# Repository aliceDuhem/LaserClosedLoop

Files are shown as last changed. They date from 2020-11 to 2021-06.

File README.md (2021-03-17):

# LaserClosedLoop

### Essential Libraries Needed:

> Ni-Visa <br />
> Visa <br />
> Guizero <br />
> ThorlabsPM100 <br />
> Pyusb <br />

### Codes needed to run (yet to interlink):

LaserControl<br />
&nbsp;&nbsp;&nbsp;&nbsp;&nbsp;&nbsp;  | <br />
&nbsp;&nbsp;&nbsp;&nbsp;&nbsp;&nbsp;  | <br />
&nbsp;&nbsp;&nbsp;&nbsp;&nbsp;&nbsp;  |-- ratioCodes (Mathematical algorithm returning angle closest to desired intensity) <br />
&nbsp;&nbsp;&nbsp;&nbsp;&nbsp;&nbsp;  | <br />
&nbsp;&nbsp;&nbsp;&nbsp;&nbsp;&nbsp;  |-- GetPower (Initialise and read power meter values) <br />
&nbsp;&nbsp;&nbsp;&nbsp;&nbsp;&nbsp;  | <br />
&nbsp;&nbsp;&nbsp;&nbsp;&nbsp;&nbsp;  |-- Motor_calibration (Motor calibration during power on) <br />
&nbsp;&nbsp;&nbsp;&nbsp;&nbsp;&nbsp;  | <br />
&nbsp;&nbsp;&nbsp;&nbsp;&nbsp;&nbsp;  |-- characteristics (Class to hold specs of the system) <br />
&nbsp;&nbsp;&nbsp;&nbsp;&nbsp;&nbsp;  | <br />
&nbsp;&nbsp;&nbsp;&nbsp;&nbsp;&nbsp;  |-- ControlCode (PID control)  <br />
&nbsp;&nbsp;&nbsp;&nbsp;&nbsp;&nbsp;  | <br />
&nbsp;&nbsp;&nbsp;&nbsp;&nbsp;&nbsp;  |-- App2 (UI for users to input desired intensity and optical properties of system) <br />

### Testing Functions:

LaserControl<br />
&nbsp;&nbsp;&nbsp;&nbsp;&nbsp;&nbsp; |<br />
&nbsp;&nbsp;&nbsp;&nbsp;&nbsp;&nbsp; |<br />
&nbsp;&nbsp;&nbsp; Tests <br />
&nbsp;&nbsp;&nbsp;&nbsp;&nbsp;&nbsp;&nbsp;&nbsp;   | <br />
&nbsp;&nbsp;&nbsp;&nbsp;&nbsp;&nbsp;&nbsp;&nbsp;  | <br />
&nbsp;&nbsp;&nbsp;&nbsp;&nbsp;&nbsp;&nbsp;&nbsp;  |-- SaveDataCsv (Function to write output array into csv for analysis) <br />
&nbsp;&nbsp;&nbsp;&nbsp;&nbsp;&nbsp;&nbsp;&nbsp;  | <br />
&nbsp;&nbsp;&nbsp;&nbsp;&nbsp;&nbsp;&nbsp;&nbsp;  |-- testDictCode (Tests dictionary to verify its theoretical functionality) <br />
&nbsp;&nbsp;&nbsp;&nbsp;&nbsp;&nbsp;&nbsp;&nbsp;  | <br />
&nbsp;&nbsp;&nbsp;&nbsp;&nbsp;&nbsp;&nbsp;&nbsp;  |-- TestDictionaryWithPowerMeter (Tests interlinkage between dictionary and power meter) <br />
&nbsp;&nbsp;&nbsp;&nbsp;&nbsp;&nbsp;&nbsp;&nbsp;  | <br />
&nbsp;&nbsp;&nbsp;&nbsp;&nbsp;&nbsp;&nbsp;&nbsp;  |-- findDifference (Tests mathematical rigour of dictionary codes) <br />

### Matlab commands to test theory:

MatlabStuff<br />
&nbsp;&nbsp;&nbsp;&nbsp;&nbsp;&nbsp;  | <br />
&nbsp;&nbsp;&nbsp;&nbsp;&nbsp;&nbsp;  | <br />
&nbsp;&nbsp;&nbsp;&nbsp;&nbsp;&nbsp;  |-- Jone1 (Made jones matrices in matlab and derived initial ratios) <br />

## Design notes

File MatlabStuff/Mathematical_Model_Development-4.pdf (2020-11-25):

# Mathematical Model of Output Intensity

November 25, 2020

## 1 Visual representation of the system

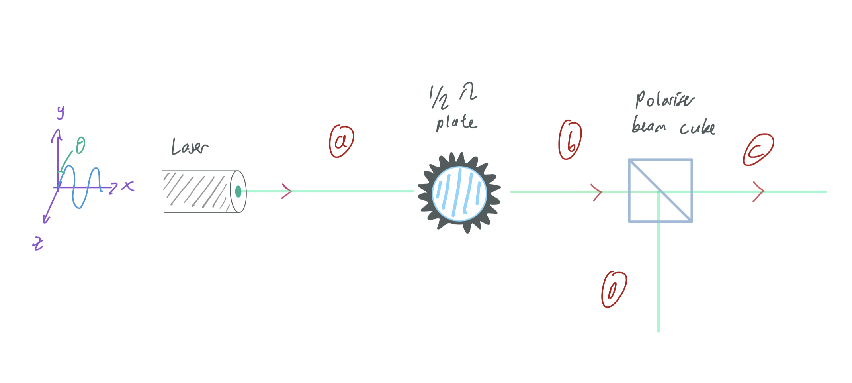
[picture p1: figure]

Figure 1: Path of laser

Figure above shows the path of the laser and the optical components which modulates it. A mathematical model of Fig.1 must be made and Incorporated into the control code so output can be tuned accordingly.

Laser Specs, CPS532-C2:

1. Output linearly polarised in the Ey direction
2. Beam diameter, 3.5mm
3. Gaussian beam
4. 532 nm, frequency changes with temprature
5. 0.9 mW Power
6. Impedance of free space, η = 376.7303Ω

Half Wave Plate Specs, WPH05ME-532:

1. reflectance 0.25% @ 532nm
2. Transmittance 98.04996% @ 532nm

Polarising Beam Cube Specs, PBS121:

1. P-pol transmittance 95.54% @ 532nm
2. S-pol transmittance 0.04348% @ 532nm (ignore too small)
3. S-pol reflectance > 99.50% @ 532nm

1

Section 3 Updates

### 1.1 Jones Matrix

A Jones Matrix for each system component has to be made. Jones matrices make it easier to look at the system as a whole as it captures both axis at the same time. It can also be thought as a transfer function.

### 1.1.1 Polarising Beam Cube

Figure 2: P=ŷ, S=ẑ

This cube allows ŷ waves to be transmitted through to C, while reflecting ẑ to path D. Thus, we can imagine the cube to have 2 polarisers, for path C in Fig.1 the fast axis is in the ŷ direction. While for path D fast axis is in zˆ.

Suppose Beam Cube from Fig.1 has a fast axis in the ŷ direction. An electromagnetic wave vector E~ can be split into it’s components.
Ey
Ez
, axis

defined in Fig.1. Now lets create its Jones Matrix. If a purely horizontally polarised EM wave passes through it, E~
x =
0
1
zˆ the output would be the nil
0
0
zˆ as incident wave is perpendicular to its axis. If a purely vertically polarised wave passes it, E~
x =
1
0

yˆ output would also be
1
0
yˆ as incident wave and fast axis align. We can combine both the output matrix

together to form the Jones matrix at Fig.1 C. J =
1 0

0 0

The above can be repeated to find the Jones matrix for the polariser in the ẑ direction.
1
0

yˆ −→
0
0
,
0
1

zˆ −→
0
1

J =

0 0

0 1
(1)

1.1.2 1/2 Wave Plate

Half wave plate works as a retarder, slowing down each of the axis independently. This is caused by bifrin-gence where the crystal has 2 different refractive indexes for each of its axis. We call refractive index in the fast axis nf and slow axis ns. In Fig.1 the fast axis of the wave plate originally lies in the ŷ direction.

A linearly polarised wave travelling in the ˆx direction can be given the equation (2). After passing the wave plate it emerges with modified terms (3) as a phase difference is introduced.

E~
x = ŷEoe

j(ωt−kx)
(2)

E~
x = ŷEoe

j(ωt−konfL)

= ẑEoe

−jkonfL
e

j(ωt−kz)

(3)

e

−jkonfL is the phase difference

ko=wave number, nf=fast axis index, L=length of waveplate, Eo=incident wave amplitude, ω=Angular frequency, t=time

Like the polarising beam cube, we intend to find the Jones matrix. So we input waves in ŷ and ẑ to find its response.
1
0

yˆ −→
e

−jkonfL
0
,
0
1

zˆ −→
0
e

−jkonsL

We combine both to make (4) which is the phase relative to incident.
e
−jkonfL | 0
0 | e −jkonsL
(4)

Multiply (4) by e

jkonfL
1 | 0
0 e

−jko(nf −ns)L

(5)

∆n = nf − ns and L =

λo
2∆n

Therefore its Jones matrix is:
1 0
0 −1
(6)

1.2 1/2 Wave Plate Rotating Jones Matrix

Jones matrix only works for a fixed theta, since our system requires the half wave plate to rotate we have to modify (6) by multiplying a rotation matrix term R(θ) to find Jnew.

Jnew = R(θ)JcurrentR(θ)

−1

R(θ) =
cos(θ) − sin θ
sin θ cos θ

(7)

By substituting (6) and finding the inverse of R(θ) we get (8) which was calculated in matlab, complex!

Jnew =

cos

π θ

180 2
− sin

π θ

180 2
2 cos

π θ
180

sin

π θ
180
2 cos

π θ
180

sin

π θ
180

sin

π θ

180 2
− cos

π θ

180 2

!
(8)

## 2 Combining it together

Order of multiplication is important, we start by multiplying leftwards components in Fig.1. Remember in this case the polarisers fast axis is in the ŷ direction.

Eoutput = Jcube ∗ Jwaveplate ∗ Einput | (9)

### 2.1 Output at Fig.1 C

(9) gives us the output amplitude as a function of θ, Ey and Ez. Notice there is no Ez term, remember the polariser is aligned with the ŷ axis so it totally blocks any ẑ component.

E~
c,out =

Ey
cos

π θ

180 2
− sin

π θ

180 2

+ 2 Ez cos

π θ
180

sin

π θ
180

0

!
(10)

### 2.2 Output at Fig.1 D

Sin | and | Cos | contained | | within | equations | | of this | paper | | are | calculated | in | radians | (matlab | default). | So | θ | which
is | in | degrees | | has | to | be | multiplied | | by | π
180 //
Remember in this case the polariser’s fast axis is in the ẑ direction. Notice that there is no Ey component as the polarising beam cube only reflects ẑ So using (9) we get

E~
d,out =

0
2 Ey cos

π θ
180

sin

π θ
180

− Ez
cos

π θ

180 2
− sin

π θ

180 2

!
(11)

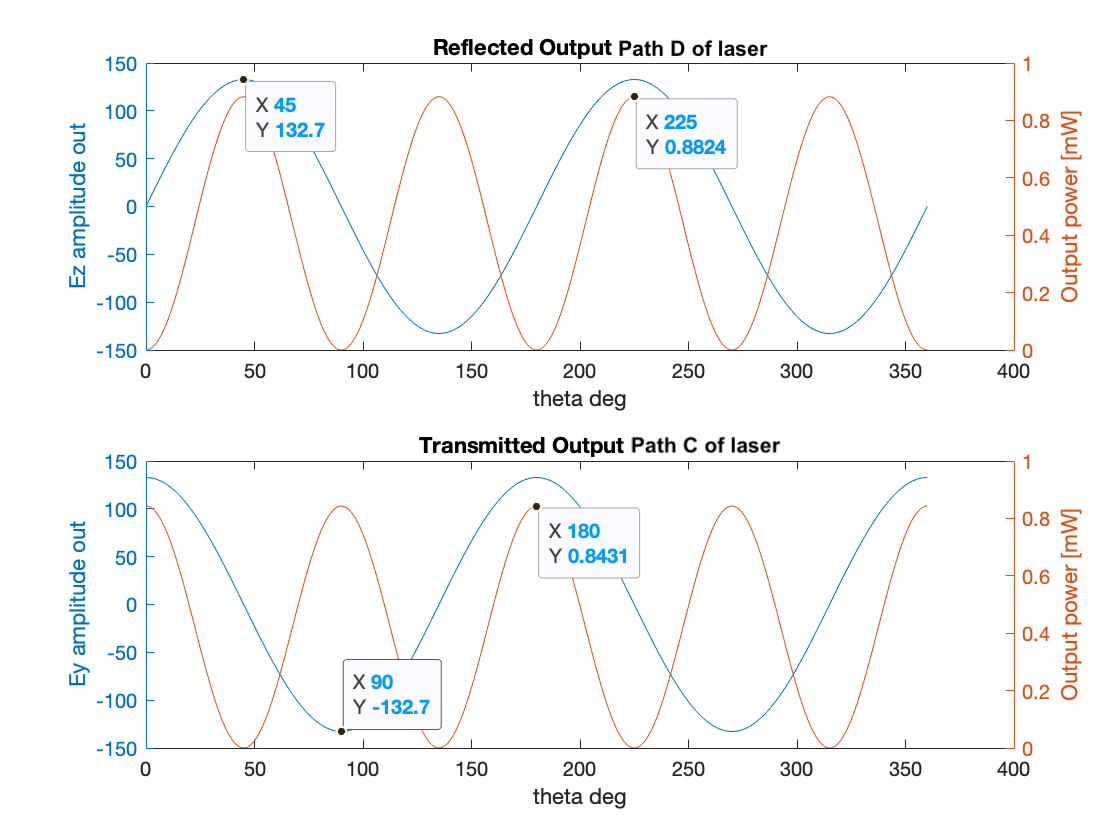
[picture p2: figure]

Figure 3: Output for Path C and D

Theta is the angle of rotation of the half wave plate relative to its fast axis pointing towards ŷ. We can theoretically sustain full range 0 to Max power with a rotation range of π/2. After including the transmission coefficients, the maximum power would be less at a max of 0.8431mW. EyandEz are phase shifted from each other by π/4.

Power of Ey also has a factor of 0.9554 multiplied to it relative to Ez (checked by isolating regions with the same shape and divided those regions, constant factor found). Both graphs are essentially the same by adding a phase shift and a factor to one of the outputs (checked by plotting with matlab).

Might | use | DTFT | to | add | time | shift, | P owerEy = 0.9554P owerEz+ | phase | shift, | π/2 | factor | is just | the | P-Pol
transmittance.

### 2.3 Equation Relating both Power at C & D

Total intensity can be found by relating eqn (10) and (11):

Itotal = Ctλt

E²
c
2η

+ λt

E²
d
2η

=

λt
2η

(CtE

2
c + E

2
d

)

(12)

ct is cube transmittance, λt is waveplate transmittance.
Total power can be found by multiplying total intensity with area:

Ptotal = Itotal ∗ BeamArea

Pc + Pd = A

λt
2η

(CtE

2
c + E

2
d

)

(13)

Expanding the above, we see that the final equation relies on 3 variables, Pc, Pd and θ in degrees.

Pc + Pd = AE²
y

λt
2η

(Ct(cos²
(

πθ
180

) − sin²
(

πθ
180

) + 4cos²
(

πθ
180

)sin²
(

πθ
180
)) | (14)

The terms after the = sign represent the fluctuating power output as a sum of both split beams. This is caused by the difference in transmittivity for P and S pol in the beam cube.

The equation (14) essentially deducts the sensor power from the total power (with regards to θ) to find power in path C.

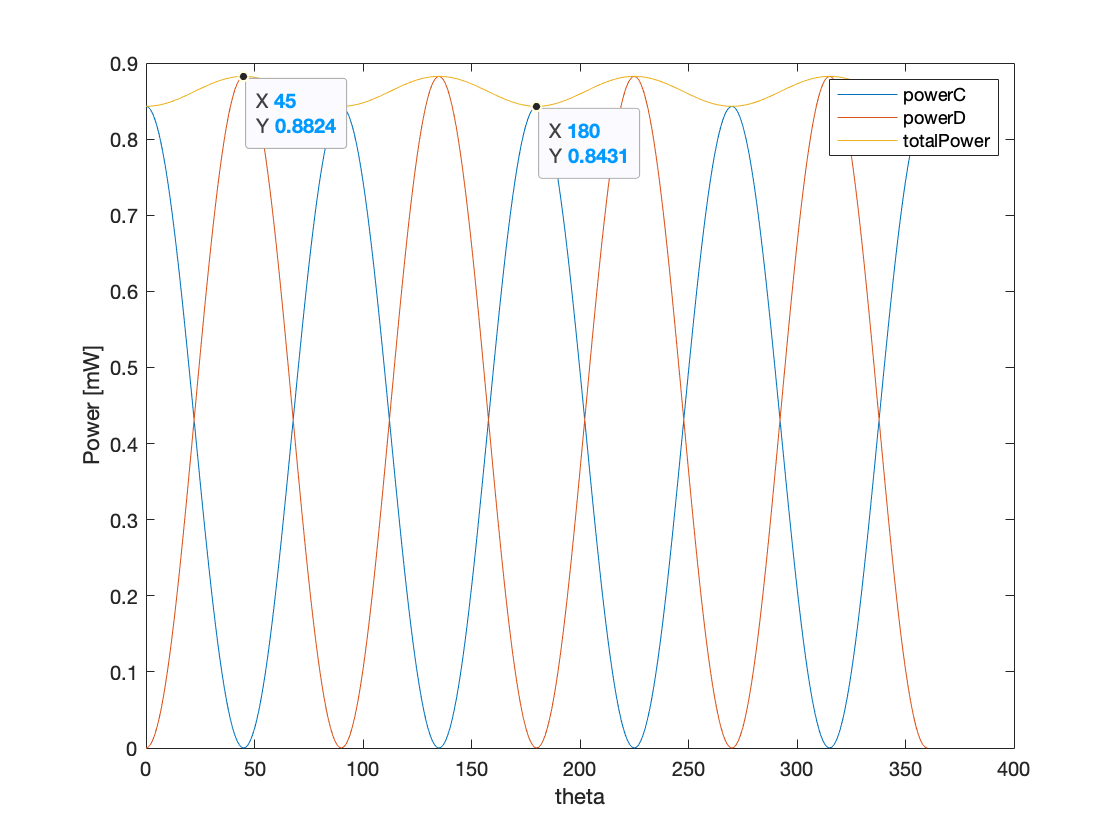
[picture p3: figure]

Figure 4: Power vs theta

UNFORTUNATELY | | | | (14) | CONTAINS | | LASER | VARIABLES | | FROM | THE | ORIGINAL | | LASER | INPUT
WHICH | IS | THEORETICALLY | | | | CONSTANT. | | THIS | DOES | NOT | TAKE | INTO | ACCOUNT | | THE | FLUC-
TUATIONS | | | OF | THE | LASER | ITSELF. | | INVERSE | | FOR | θ | HARD | TO | FIND | as | shown | in | the | long | equation
(15) below

−

ln

16384000 √
(500000 T Z−4405109641 A L) (137438953472 T Z−1210867317976915 A C L)−4294967296000000 T Z+18919801843389300736 A L+18919801843389296875 A C L
18919801843389300736 A L−18919801843389296875 A C L | 1/4

π
(15)
3 | POSSIBLE | BREAKTHROUGH

Looking at figure 3. There is a possible connection between both output power except the obvious phase shifts.

By dividing powerC/powerD I get the figure below. This does not change with the change with different laser intensity. The transmittance of the optical elements cause it to change as explained below.

intensity =

E

2
2η
power = intensity ∗ area

Since we’re dividing Power C by Power D, and beam area is assumed to be constant, the area cancels out. This gives us the individual intensities for both path C and D. Don’t forget to multiply by transmittance of half wave plate λt and cube Ct.

ID = λt

E²
z
2η

IC = λtCt

E²
y
2η
Ratio, PC
PD

=

IC
ID

= Ct

E²
y
E²
z

(16)

We get the ratio which can be seen in Fig. 5. Ratio changes with theta and at multiples of 0, 45 deg the ratio will be 0. So this means at multiples of 0 and 90 deg power D will be 0. This is the same for power C at multiples of 45 deg. This can be confirmed by referring to Fig. 3

Ratio scaled based on cube transmittance Ct and not half wave plate as they cancel out. If the cube reflected tramsmittance is significant, te scale would instead be, Ct Ref.T rans.

We now can relate the Power C and Power D without the original laser input. This can be done by checking the motor angle and referring to the ratio dataset to calculate the corresponding power. The datapoints can be found in github to be used! https://github.com/aliceDuhem/LaserClosedLoop

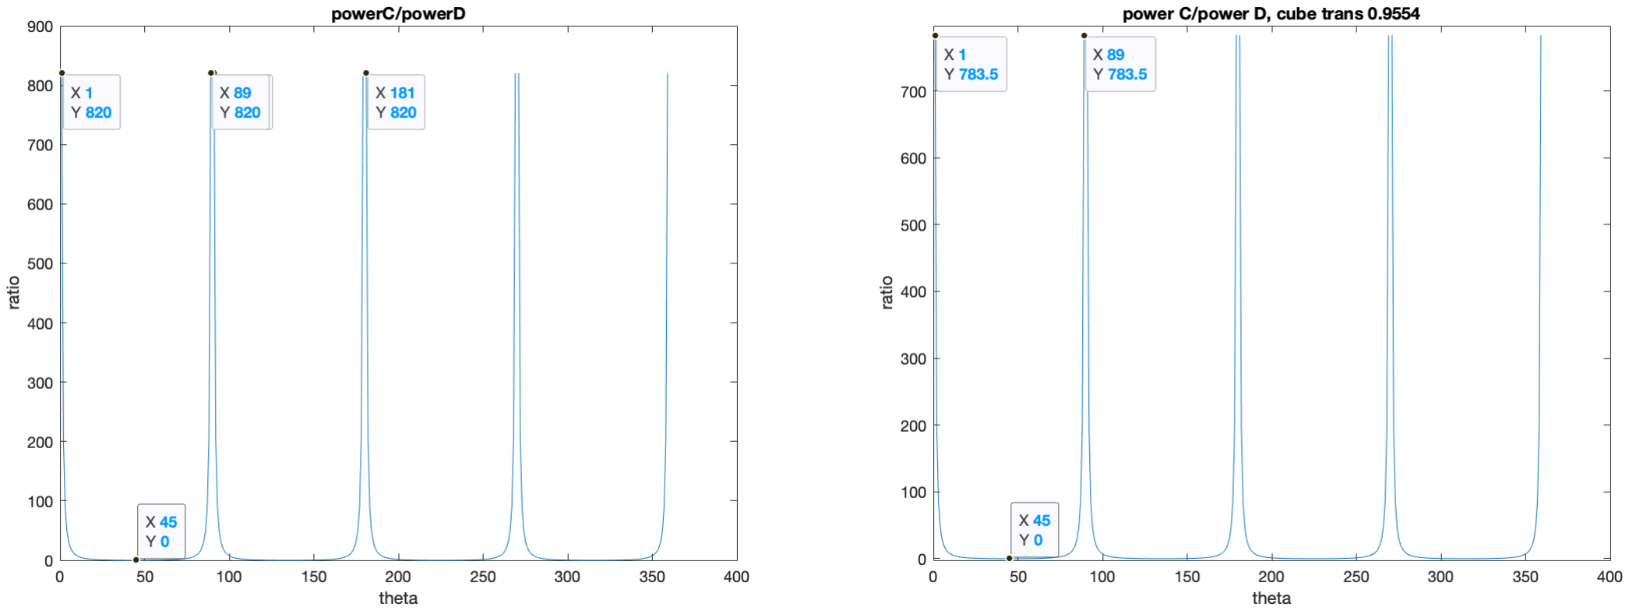
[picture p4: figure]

Figure 5: PowerD:PowerC

4 | Comparison with Malus Law | Ignore

Malus Law states that output intensity, Io, is proportional to cos² θ, when a wave passes a linear polariser.

Io = Iin cos²
θ | (17)

In Fig.6 we can see that Jones has an angular velocity twice that of Malus. Transmission coefficients have been incorperated into the calculations for the graph. Both have the same peak, thus we are able to model ALL the above with (18) instead, but keep in mind to add the transmission coefficients.

Io = Iin cos²
2θ | (18)

Iin contains the original intensity, cube P-pol transmittance, wave plate transmittance.

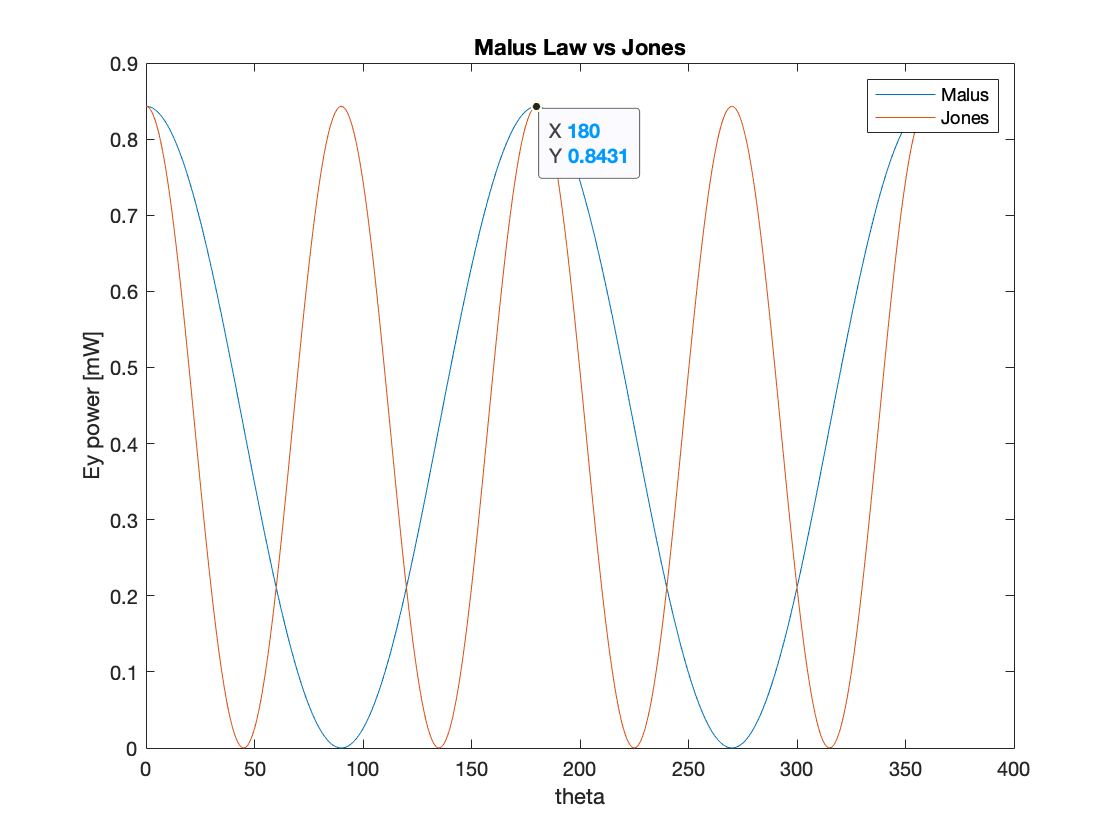
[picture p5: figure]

Figure 6: Malus VS Jones in Path C

## Appendix A MATLAB Code

clc
clear all
close all

% polarizing beam cube errors and specs (reflects s-pol) % p-pol transmittance 95.54% @ 532nm
% s-pol transmittance 0.04348% @ 532nm
% total R_s > 99.50%
cubeP_trans = 0.9554;
cubeS_trans = 0.0004348; %this not needed as the max difference in power is 3.83e-4 mW

% half wave plate errors and specs
% reflectance 0.25% @ 532nm
% transmittamnce 98.04996% @ 532nm

halfWave_trans = 0.9804996; % incldue as mean sqr err between original and transmitted Ey ,→ = 0.8482

% laser spec and error
% 0.8mW < power < 1mW, typical @ 0.9mW % frequency changes with temprature

%% Find transmitted output Ey

% use jones matrix to find 'transfer function' of whole system

syms theta Ey Ez;

r = [cosd(theta) -sind(theta);sind(theta) cosd(theta)]; rInv = inv(r);

JonesHalf = [1 0;0 -1];
JonesPol=[1 0 ; 0 0];
JonesHalfRot = r*JonesHalf*rInv;
initial =[Ey; Ez]; % only adjust Ey becsaue laser linearly pol. % keep Ez as 0, laser pol in Y direc only. % adjust in bottom {} brackets
TotalTrans = JonesPol*JonesHalfRot | * initial;
thetaAxis =[0:1:360]; | % adjust division accodring to servo motor

for i=1:size(thetaAxis,2)

solT = subs (TotalTrans, {theta, Ey,Ez} ,{thetaAxis(i),132.742,0});

outEy(i) = double(solT(1));
outEz(i) = double(solT(2));
end

% plot theta against Ey proportion
% Ez remains 0 as 2nd polariser cuts it off figure(1)
subplot(2,1,2)

yyaxis left
plot(thetaAxis,outEy)
xlabel('theta')
ylabel('Ey amplitude out') title('Transmitted Output Ey of laser')

hold on
intensity = cubeP_trans .* halfWave_trans .* outEy.^2 ./ (2.*376.7303); %include transmittance above
power = intensity .* (pi.*(3.5e-3.^2));

yyaxis right
plot(thetaAxis,power.*1000) xlabel('theta deg')
ylabel('Output power [mW]')

%% test with malus law instead of jones

intensity1 = 0.9e-3 / (pi*(3.5e-3^2));
intensity1Out = cubeP_trans .* halfWave_trans .* intensity1 .* cosd(thetaAxis).^2;

figure plot(thetaAxis,intensity1Out.*1000.* (pi.*(3.5e-3.^2)),thetaAxis, power.*1000) legend('Malus','Jones')
ylabel('Ey power [mW]')
xlabel('theta')
title('Malus Law vs Jones')

% intensity - intensity1Out gave a mean squared error of 1.5903e-10, which % is neglegable. So i suggest we ignore it.
% this shows that my equations are very close to malus law

%% reflected output Ez to detector

JonesPolRef=[0 0 ; 0 1];
JonesHalfRot = r*JonesHalf*rInv;
TotalRef = JonesPolRef * JonesHalfRot * initial;

for i=1:size(thetaAxis,2)

solT = subs (TotalRef, {theta, Ey,Ez} ,{thetaAxis(i),132.742,0});

outRefEy(i) = double(solT(1));
outRefEz(i) = double(solT(2));
end

figure(1)
subplot(2,1,1)
yyaxis left
plot(thetaAxis,outRefEz)
xlabel('theta')
ylabel('Ez amplitude out') title('Reflected Output Ez of laser')
hold on

intensityRef = halfWave_trans.* outRefEz.^2 ./ (2.*376.7303); powerRef = intensityRef .* (pi.*(3.5e-3.^2));

% figure
yyaxis right
plot(thetaAxis,powerRef.*1000) xlabel('theta deg')
ylabel('Output power [mW]')
% title('Power vs theta')

%% Ez and Ey between half wave and cube

between = JonesHalfRot * initial;

for i=1:size(thetaAxis,2)

solBet = subs (between, {theta, Ey,Ez} ,{thetaAxis(i),132.742,0});

BetEy(i) = double(solBet(1));
BetEz(i) = double(solBet(2));

end

figure
hold on
plot(thetaAxis, sqrt(halfWave_trans).* BetEy, thetaAxis, sqrt(halfWave_trans).*BetEz) plot(thetaAxis, BetEy, thetaAxis, BetEz)
% legend('Ey','Ez')

%% plot path C including s-pol
% cannot use equaton outEY as that contains final transform % can ignore as difference too small 1e-4 mW in power

FinalEz = BetEz.*sqrt(halfWave_trans).*sqrt(cubeS_trans); FinalEy = BetEy.*sqrt(halfWave_trans).*sqrt(cubeP_trans); % outEy = outEy .* sqrt(halfWave_trans);

Etot = sqrt(FinalEz.^2 + FinalEy.^2);

intensityNew = Etot.^2 ./ (2.*376.7303); powerNew = intensityNew .*(pi.*(3.5e-3.^2)); figure
plot(thetaAxis, powerNew*1000)

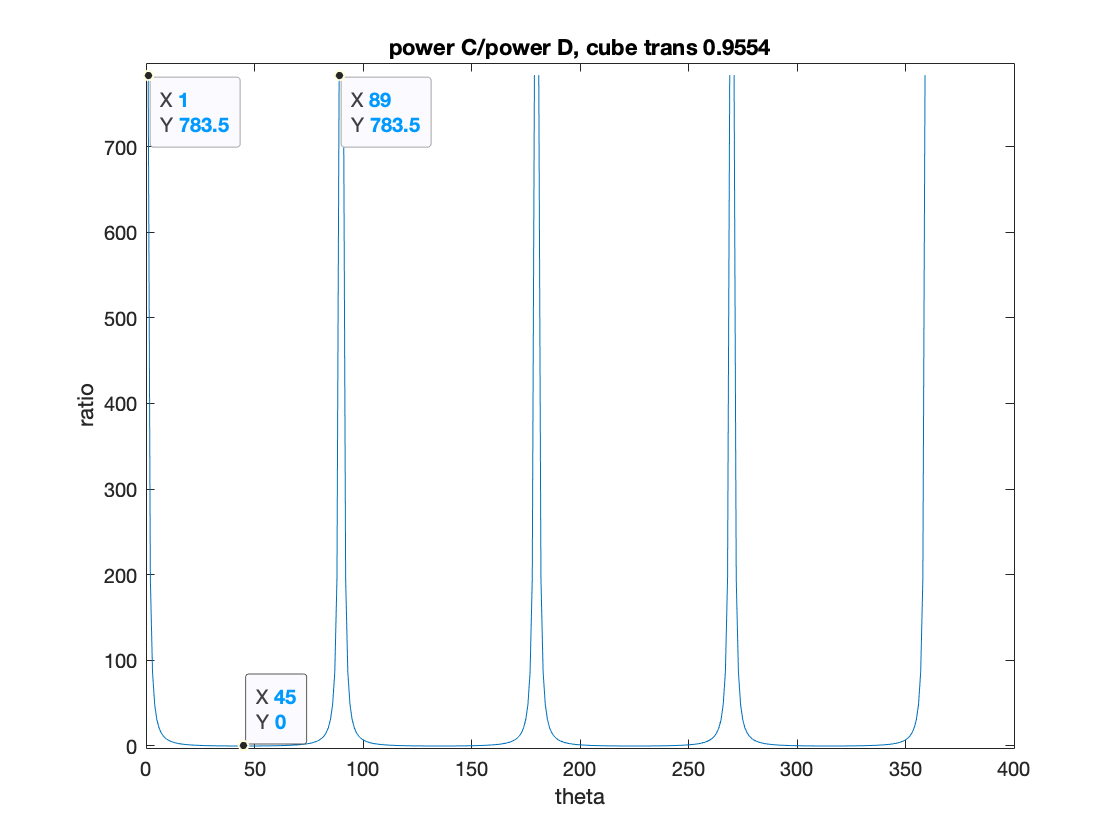
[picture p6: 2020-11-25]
MatlabStuff/ratio1.png

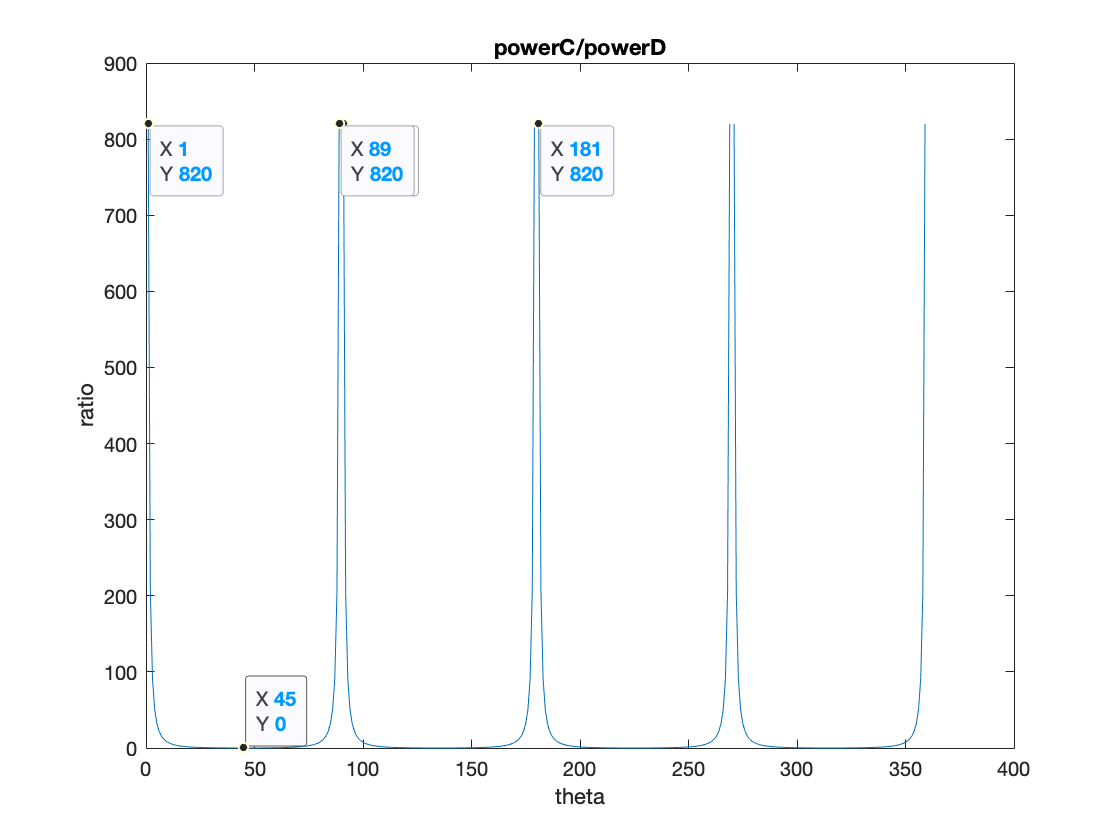
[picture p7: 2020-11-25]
MatlabStuff/ratio.png

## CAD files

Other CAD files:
Solidwork mechanical stands parts/Beam cube case/final_beam_cube.ipt
Solidwork mechanical stands parts/Beam cube case/final_beam_cube_top.ipt
Solidwork mechanical stands parts/HWP rotating mount/Bottom_stand_HWP_Tube.ipt
Solidwork mechanical stands parts/HWP rotating mount/Top_stand_HWP_Tube.ipt
Solidwork mechanical stands parts/Laser case/laser bottom.ipt
Solidwork mechanical stands parts/Laser case/laser top.ipt
Solidwork mechanical stands parts/Linear Polariser case/linear polariser.ipt
Solidwork mechanical stands parts/bottom_platform/platform_part_1.ipt
Solidwork mechanical stands parts/bottom_platform/platform_part_2.ipt

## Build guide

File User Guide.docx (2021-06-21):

User Guide to the device

Components needed

- Power meter and a photodiode power sensor: Reads the laser power refracted from the beam cube
- Optics:
  - Polariser: linearly polarise the light in case the laser is elliptically polarised
  - Half Wave Plate: Changes the polarisation angle of the linearly polarised light
  - Beam Cube: Separates the vertical and horizontal components of the incident light
- Access to a 3D printer and laser cutter to print and cut the stability equipments and gears
- Motor Control:
- Raspberry Pi (you can also use an Arduino UNO)
- Stepper motor with 0.9° increments
- Motor driver (for example A4988)
- Breadboard, PCB or stripboard and wires

Mechanical Stands:

1. Open the CAD models of the stands
2. Dimension the stand parts such that they can fit your optics’ dimensions
3. 3D print the stand elements
4. Buy an aluminium tube of the same outer diameter than the tube holder (D). Make sure that the inner diameter of the aluminium tube can hold the half wave plate. The default design required a 20mm outer diameter.
5. Drill at the end of the tube (where the Half wave plate is positioned), three equidistant holes. Place some small screws to hold the half Wave Plate (the Half wave plate must be already mounted
6. Laser Cut the gears and the main stand using at least a 5mm plastic (acrylic, polypropylene). You can also glue two identical pieces of smaller diameter.
7. Mount the system according to picture 1

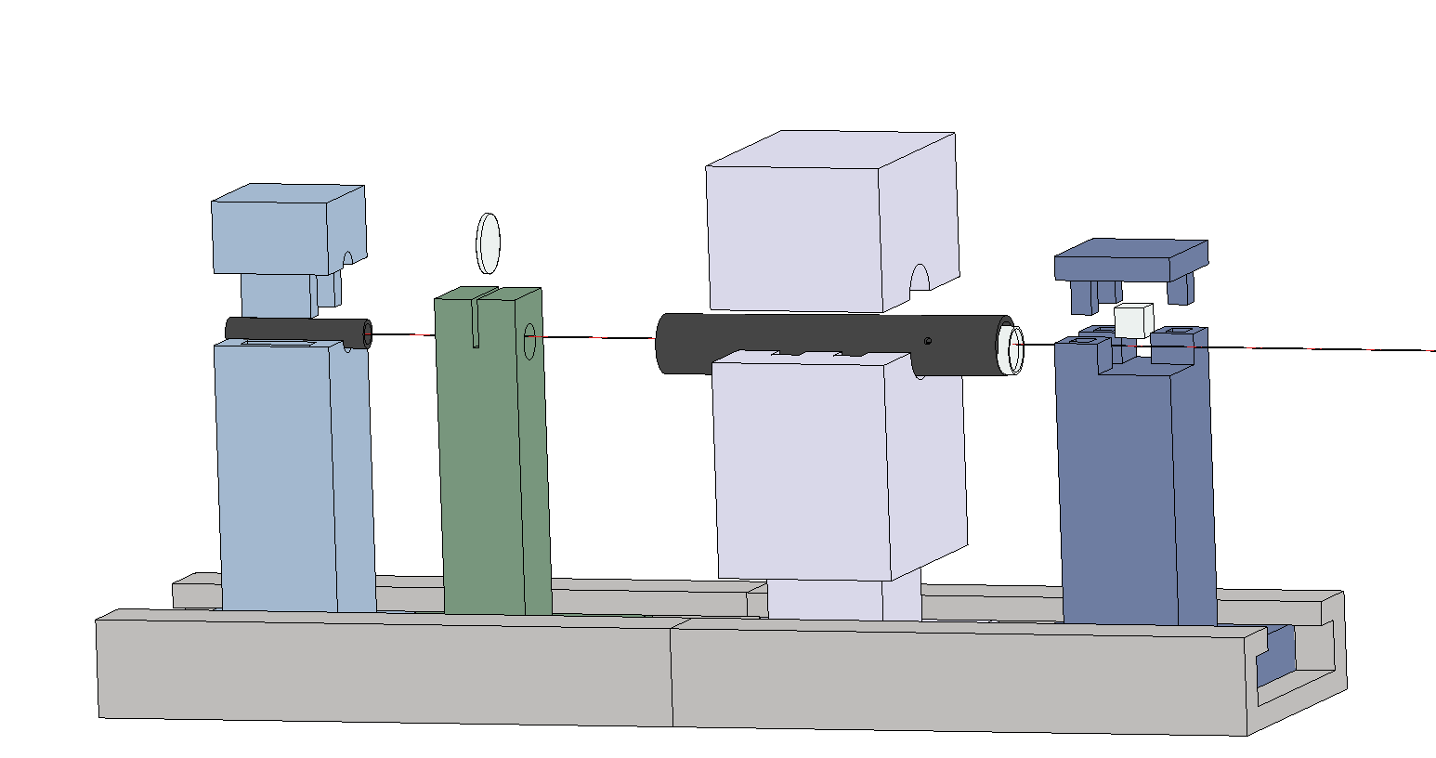
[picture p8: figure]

Picture 1: Mounted mechanical stands

From left to right (A) Laser holder(B) Linear Polariser holder (C) Half Wave plate holder (tube) [and (D) its mount] (E) Polarising Beam Cube holder

Software:

Download the codes

Clone the Github repository to download the code on your computer. The ‘Final’ branch is the latest developed. Some areas still need to be developed and have not been fully tested (PID loop) as the motor was most likely faulty during the tests.

Several libraries need to be added to use of the software:

- If you are using a Thorlabs PM100D power meter, download the ThorlabsPM100 package and follow the instructions: https://pypi.org/project/ThorlabsPM100/. This package requires the pyvisa package to control the instrument: https://pyvisa.readthedocs.io/en/stable/, and the National Instrument Visa Library, https://www.ni.com/engb/support/downloads/drivers/download.ni-visa.html#346210
- The remaining libraries used are usually provided when downloading Python

Information on the code

Connecting the Power Meter

- The Power Meter must be plugged in the computer via USB. The class ‘PowerMeter’ in GetPower.py is used in the main code to initialise and read values from the power meter. The example is given for Thorlab’s PM100 power meter. This class is abstracted, hence, you can easily change the initialisation to use a different device by just updating the class to meet your power meter’s requirements.
- The function __init__(self) initialises the device.
- usb_port = rm.list_resources() reads the components plugged to your computer and rm.open_resource(usb) opens them.
- self.power_meter = ThorlabsPM100(inst=inst) creates an instance of the power meter object with as power meter, the one opened from the USB.
- The function readPower reads the power from the power meter by calling the power meter’s library functions.

Running the program

- App3.py is the main function of the code. It calls the required libraries and packages used for the functioning of the device.
- The User Interface was designed using the library Tkinter. Threading is used to start and stop the device when the respective buttons are clicked.
- The timed data from the power meter are then saved in a CSV file.

Connecting the Microprocessor to the motor

We have not been able to test this properly as the motor or the motor driver were faulty during the experiments. The connection codes are in ConnectionTestArduino.py (Arduino) and ConnectionR.py (Raspberry Pi)

In ConnectionTestArduino.py, change the name of the port to the name of the port in your Arduino

In ConnectionR.py change in the class connection the UDP_IP_COMPUTER to the IP address of your computer, and UDP_IP with the IP address of your Raspberry Pi (Which needs to be connected to internet)

Information to connect an Arduino to a motor and drive the motor from the Arduino can be found here: https://howtomechatronics.com/tutorials/arduino/how-to-control-stepper-motor-with-a4988-driver-and-arduino/

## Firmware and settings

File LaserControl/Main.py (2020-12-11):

# This code represents the main of the program
# It includes:
# The class that gets the power from the power_meter
# The class that displays that ask the power from the user
# The class that compares the values and comes up with an output angle
# The class that sends the output to the RaspberryPi for actuation

#-------------------------------------------------------------------------------
#All the libraries used int the code (visa, Thorlabs, guizero)

#libraries for the power meter
import visa
from LaserControl.GetPower import PowerMeter
#libraries for the app display
from guizero import App,Text,TextBox, PushButton
#-------------------------------------------------------------------------------

#All the constant values required in the code

#%error tolerated regarding the intensity
ERROR = 0.05
#The time between two readings in ms
TIME_BETWEEN_TWO_READINGS = 1000
#actuation time after which reading is taken, need to determine experimentaly
ACTUATION_TIME = 100

#-------------------------------------------------------------------------------
#Start by creating the power meter  using VISA
power_meter = PowerMeter()
power_meter.createInstrument()


#-------------------------------------------------------------------------------
#Ask the user for the wanted intensity
#see code in App.py, will add later
#we get \/
outputValue

#This value is set by the user in the App.py
Target_power = outputValue
#Compute the error we authorise, so get outputValue_min and outputValue_max
#-------------------------------------------------------------------------------
#Definition of the PID controller
#The values will need to be set with the formula
KP = 0.02
KD = 0.01
KI = 0.005

power1_prev_error = 0
power1_sum_error = 0
angle = 0
a = 0 #a will be the factor by which we will multiply a power value to get the corresponding angle
# we still need to figure out what a actually is
# This shuld call a lookup table

#-------------------------------------------------------------------------------
#status_on tells if the program is shut or not, it is initially on so True
#TODO: create a status function
status_on = True;

while (status_on):
    #Get the power of the power_meter
    actual_power = print(power_meter.read)

    power1_error = Target_power - actual_power.value
    actual_power += (power1_error * KP) + (power1_prev_error * KD) + (power1_sum_error * KI)
    dtheta = a*power1

    power1_prev_error = power1_error
    power1_sum_error += power1_error
    power1.reset()
    sleep(ACTUATION_TIME)


    #This is another way I thought of doing it, tell me which one you prefer
    # experimental_power = print(power_meter.read)
    # power1_error = Target_power - experimental_power.value

    # if power1_error>ERROR:
        # experimental_power += (power1_error * KP) + (power1_prev_error * KD) + (power1_sum_error * KI)
        # dtheta = a*power1
        #TODO: USE A FTP TO SEND DTHETA TO THE RPI
        # power1_prev_error = power1_error
        # power1_sum_error += power1_error
        # sleep(ACTUATION_TIME)
    # else:
        # sleep(TIME_BETWEEN_TWO_READINGS)


    #TODO: put another function in for the status which checks the power meter is on
    #And throws an error if not, etc

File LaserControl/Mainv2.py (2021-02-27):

# Power on the RPi
# Ask the user for a power value (as area is constant and intensity is power*Area and we use the ratio)

# Rotate to 0

# Put the correct angle and remember the angle_motor

# Make the dictionary (for optical components)

#Loop:
    # Reads the value from the power PowerMeter
    # Make the new dictionary based on the Pd you have
    # Find Pc from measured Pd
    # Calculate the error from PC (entered-Pc computed)
    # Define a new target power (Calculated from PID: target = Pc*(error*Kp(PID coeff)+past_error*Kd+sum_past_error*Ki)
    # From target power, find new angle (with the second dictionary - same code as V.1 but change the wantyed Intensity)
    # Enters in the Pd to max code
    # Find the angle of intended rotation from target power
    # Send the angle to RPi (with GIPO-0)
    # Deconstruct the second dictionary
    # Write values in CSV (or in data array)
    # Write value on User GUI
#end of the loop

# Optionanl - send back to 0
# Write the values in CSV file for data analysis
# Destroy main DICTIONARY
# Shut RPi

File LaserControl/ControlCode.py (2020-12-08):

#This part of the code compares the experimental value and the requested one

#outputValue refers to the requested value from the code App.py
#experimental_value refers to the value obtained from the power meter in GetPower.py

#The output of this part is an angle theta sent to the RPI

#Definition of the PID controller
#The values will need to be set with the formula
KP = 0.02
KD = 0.01
KI = 0.005
#This value is set by the user in the App.py
Target_power = outputValue #mW

power1_prev_error = 0
power1_sum_error = 0
angle = 0
a = 0 #a will be the factor by which we will multiply a power value to get the corresponding angle
# we still need to figure out what a actually is

while (status_on):
    power1_error = Target_power - power1.value
    power1 += (power1_error * KP) + (power1_prev_error * KD) + (power1_sum_error * KI)
    dtheta = a*power1 
    servo.angle = dtheta
    power1.reset()
    sleep(SAMPLETIME)
    power1_prev_error = power1_error
    power1_sum_error += power1_error

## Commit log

2021-01-27 Add files via upload
    added functions to convert csv to Dict, and if there is no csv file
    we can generate own ratio dict from motor intervals
2021-01-29 Read data from a file for tests
    [intensity_readings_2021-Jan-29_21-34-11.csv]
2021-01-30 Test generation function, create fake data, small changes in generation function
    [fake_intensity_data_test.csv]
2021-01-31 Test time vlookup for 1000 data
    [intensity_readings_2021-Jan-31_19-49-26.csv, intensity_readings_second_2021-Jan-31_19-38-54.csv]
2021-01-31 Change intensity range (from calculations in log book)
    [fake_intensity_data_test.csv]
2021-02-08 Changed the folder of the tests and data of the tests
    [fake_intensity_data_test.csv, intensity_readings_2021-Jan-31_19-48-40.csv, intensity_readings_2021-Jan-31_19-49-26.csv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]
2021-02-08 Brings half wave plate to 0
2021-02-15 Code that goes from 0 to the wanted intensity at calibration
2021-02-19 App 2 has a single validation button
2021-02-20 New commands power
2021-02-24 New function (to finish later), uses threading
2021-02-26 Tested with power meter and it works (deleted timeout)
2021-02-27 Code to read the power meter value when no HWP
2021-02-27 Test for the angle needed (Dictionary) - Free running bean
    [DictionaryTest1.csv, DictionaryTest2.csv, DictionaryTest3.csv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]
2021-02-27 Change in power free running bean
    [FreeLaserExp1.csv, FreeLaserExp2.csv]
2021-03-01 Test 28/02
    [AnalysisResults_TestDict_28_02_motorInc_01.xlsx, Analysis_Results_TestDict_28_02_motorInc_09.xlsx, DictionaryTest1.csv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]
2021-03-01 Tests 01/03
    [Analysis_Results_TestDict_01_03_motorInc_01.xlsx, Analysis_Results_TestDict_01_03_motorInc_09.xlsx, Test_Dictionary_motorInc_01_wantedPower_0025_2021-Mar-01_18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]
2021-03-03 added check to return max power if Pc>wanted
2021-03-04 Issue MIGHT be fixed, needs validation
    [Test_Dictionary_motorInc_09_wantedPower_5_2021-Mar-03_23-20-33.csv, Test_Dictionary_motorInc_09_wantedPower_5_2021-Mar-03_23-21-45.csv, Test_Dictionary_motorIn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]
2021-03-07 fixed minor stuff, need to validate code
    [ratioCodes.py]
2021-03-08 fixed exception ar 45 deg, and wanted>maxPower
    [ratioCodes.py]
2021-03-10 change power bounds
2021-03-10 Results test 10/03/21
    [power_readings__motorInc0.2_2021-Mar-10_09-33-33.csv, power_readings__motorInc0.2_2021-Mar-10_09-37-27.csv, power_readings__motorInc0.2_2021-Mar-10_09-39-36.csv]
2021-03-12 Test code finding Pc
    [FreeLaserExp2b.xlsx, power_readings__motorInc0.2_2021-Mar-11_12-04-29.csv]
2021-03-13 minor formula tweaks!
    [power_readings__motorInc0.2_2021-Mar-10_18-34-37.csv]
2021-03-15 Results tests
    [change in power vs angle HWP.xlsx, motorInc_0.1_narrow_whole_range.xlsx, motorInc_0.1_over_whole_range.xlsx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]
2021-03-15 change folder test march 14
    [power_readings__motorInc0.1_2021-Mar-14_18-40-48.csv, power_readings__motorInc0.1_2021-Mar-14_21-59-59.csv, power_readings__motorInc0.2_2021-Mar-14_18-08-55.cs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]
2021-06-19 Connection Test Arduino
2021-06-19 Necessary code only
    [AnalysisResults_TestDict_28_02_motorInc_01.xlsx, Analysis_Results_TestDict_01_03_motorInc_01.xlsx, Analysis_Results_TestDict_01_03_motorInc_09.xlsx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]
2021-06-21 Connection Arduino
